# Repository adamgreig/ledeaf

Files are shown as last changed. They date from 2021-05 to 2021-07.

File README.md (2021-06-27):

# LEDEAF

A modular LED light inspired by [@GeekMomProjects]' project. Compared to the
original, this version:

* is drawn from scratch in KiCad
* uses the attaching bolts for electrical contact, instead of spring contacts
* only requires one acrylic sheet per triangle
* all LEDs on each panel are driven by the same input data

[@GeekMomProjects]: https://twitter.com/GeekMomProjects/status/1269671840512794624

The project is designed for complete SMT assembly by JLCPCB.

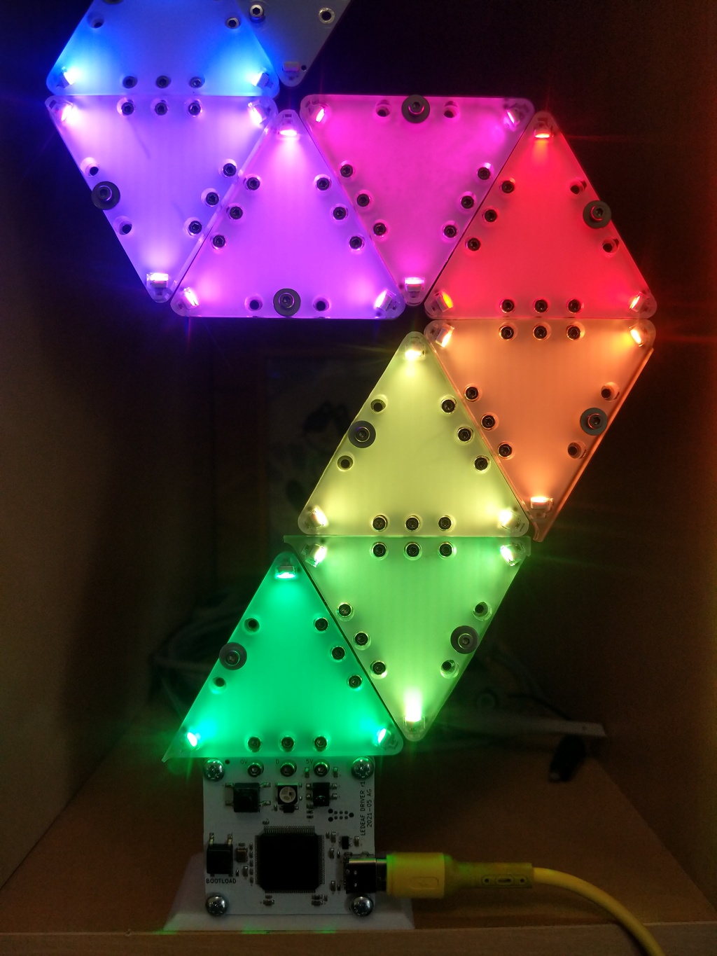
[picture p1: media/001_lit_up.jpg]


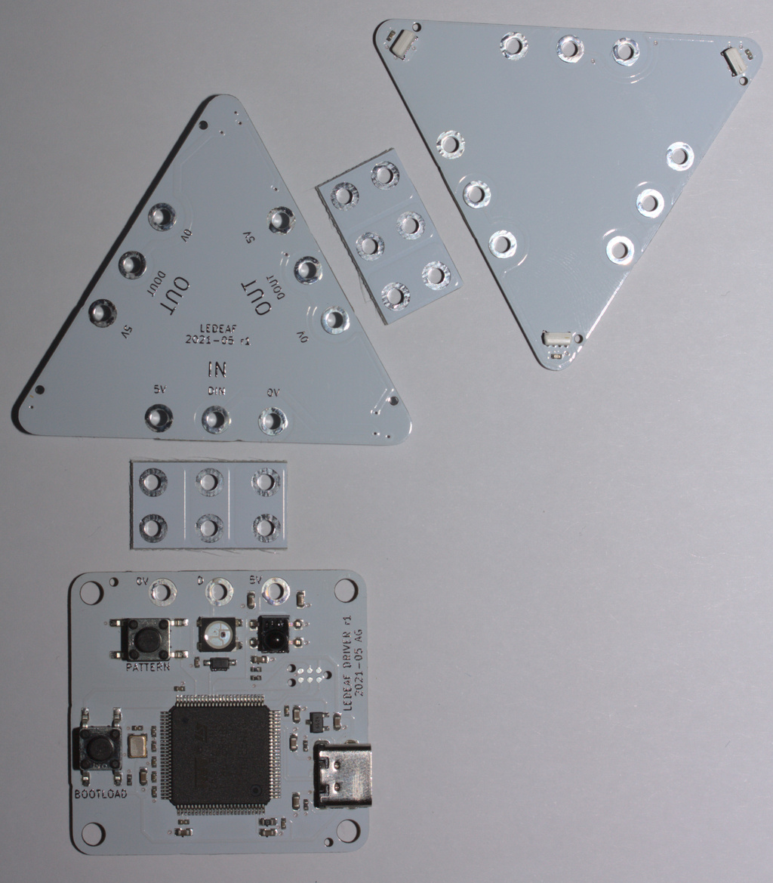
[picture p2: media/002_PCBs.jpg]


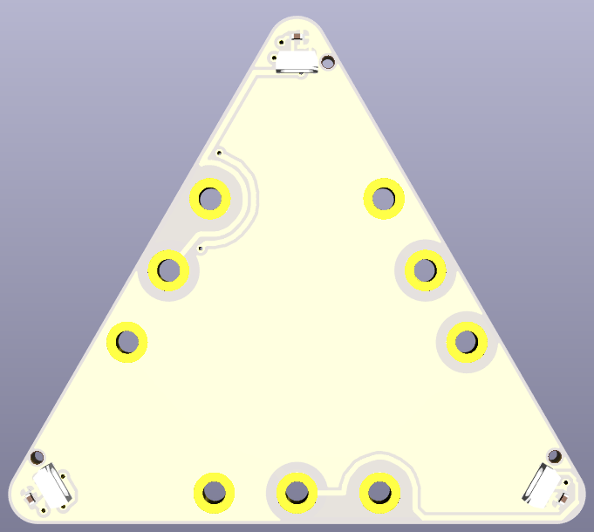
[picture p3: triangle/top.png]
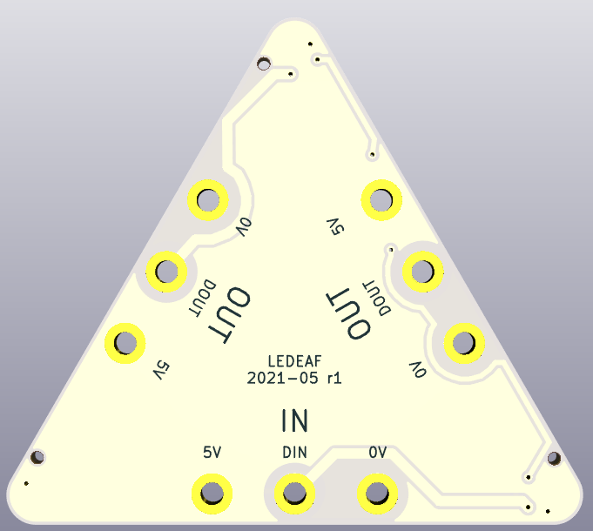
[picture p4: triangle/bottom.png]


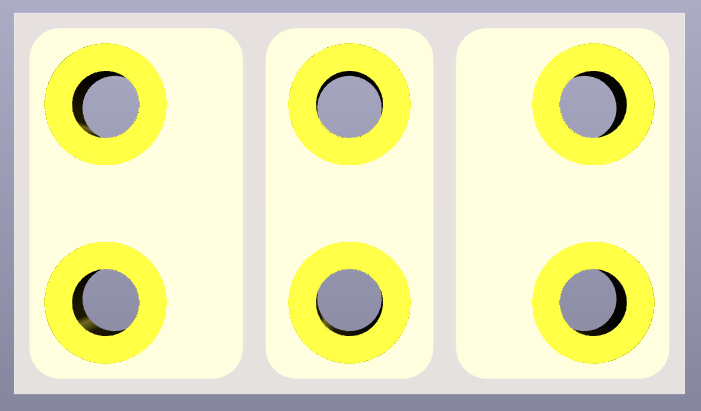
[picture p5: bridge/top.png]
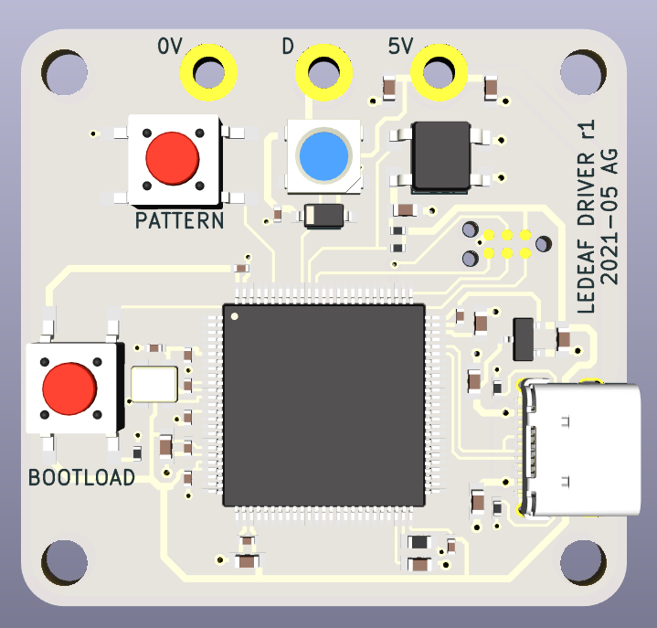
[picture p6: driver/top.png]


## License

Hardware designs licensed under the [CERN-OHL-P v2].

[CERN-OHL-P v2]: LICENSE_CERN_OHL_P_v2.txt

> You may redistribute and modify this documentation and make products
> using it under the terms of the CERN-OHL-P v2 (https:/cern.ch/cern-ohl).
> This documentation is distributed WITHOUT ANY EXPRESS OR IMPLIED
> WARRANTY, INCLUDING OF MERCHANTABILITY, SATISFACTORY QUALITY
> AND FITNESS FOR A PARTICULAR PURPOSE. Please see the CERN-OHL-P v2
> for applicable conditions

Software licensed under the [Mozilla Public License].

[Mozilla Public License]: LICENSE_MPL.txt

> This Source Code Form is subject to the terms of the Mozilla Public
> License, v. 2.0. If a copy of the MPL was not distributed with this
> file, You can obtain one at https://mozilla.org/MPL/2.0/.

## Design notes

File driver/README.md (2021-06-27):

# ledeaf driver

This directory contains the PCB design for the driver board.

## Revision 1: 2021-05

### Errata

* Issue going into USB bootloader possibly because BOOT1 (PB2) is floating,
  maybe add a pull-down resistor.

### Thoughts For Next Rev

* Combine BOOTLOAD and PATTERN buttons into one (wire BOOT0 up to a GPIO)
  to reduce BOM count.
* Investigate cheaper STM32 and oscillator.
* Add light sensor to allow automatically scaling brightness.

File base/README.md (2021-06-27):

# 3d Printed Base

This directory contains a design for a 3d printed holder for the driver PCB,
able to support a smallish stack of triangles. It has been printed successfully
in PLA, using M3 threaded heat-set inserts to attach to the driver PCB.

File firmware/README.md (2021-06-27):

# LEDEAF Firmware

Firmware for LEDEAF. Written in Rust.

## Build Requirements

* You must have a working Rust compiler installed. Visit
[rustup.rs](https://rustup.rs) to install Rust.

* Your Rust toolchain needs the `thumbv7em-none-eabihf` target installed:

```
rustup target add thumbv7em-none-eabihf
```

## Building and Flashing

To build the current firmware and flash using a connected probe, install
[`cargo-embed`](https://crates.io/crates/cargo-embed) and then run:

```
cargo embed --release
```

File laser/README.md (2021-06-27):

# Laser Cutter Drawings

This directory contains drawings for laser cutting the frosted acrylic top
covers for the triangle PCBs. The design material is a frosted/translucent 3mm
acrylic, but other thicknesses or styles could work.

One acrylic triangle is required per triangle PCB.

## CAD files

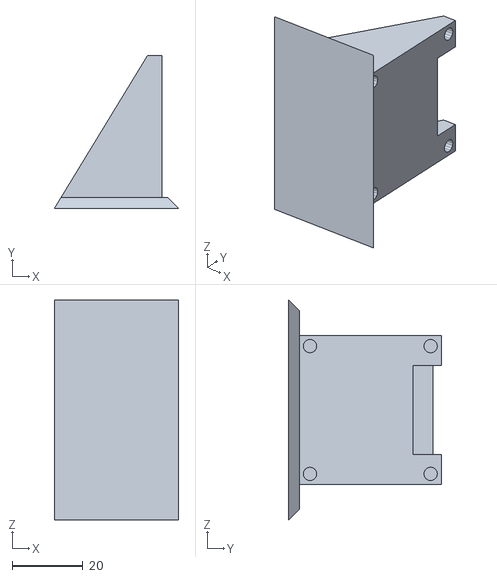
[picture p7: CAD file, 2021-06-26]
base/base.stl
35.0 x 43.0 x 62.0

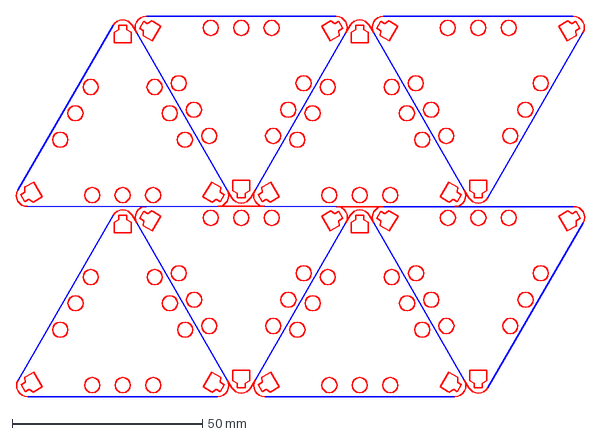
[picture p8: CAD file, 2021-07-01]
laser/cover_100x150.dxf
149.6 x 99.9 mm

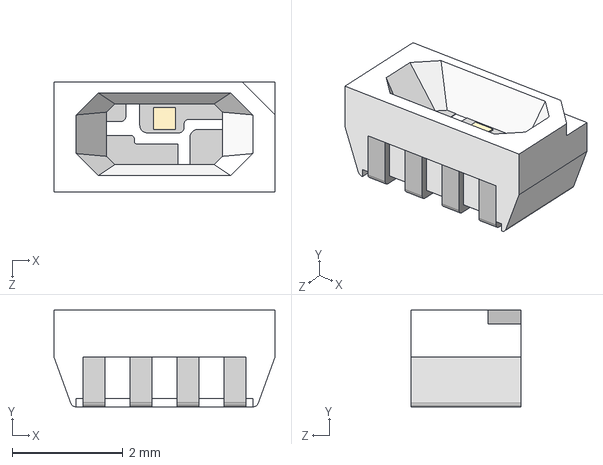
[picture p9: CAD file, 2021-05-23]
triangle/ws2812-4020.step
4.00 x 1.75 x 2.00 mm

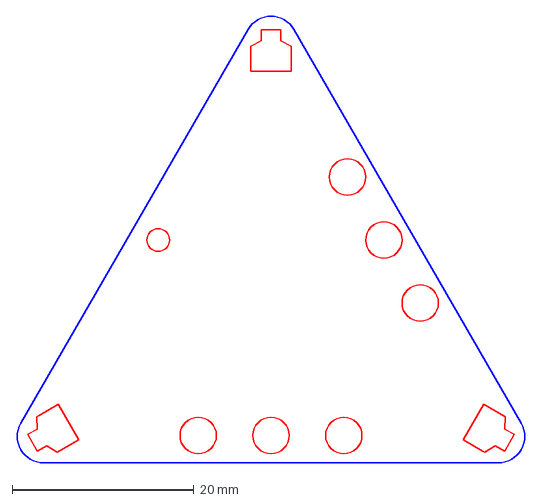
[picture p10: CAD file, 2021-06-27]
laser/cover.dxf
56.0 x 49.1 mm

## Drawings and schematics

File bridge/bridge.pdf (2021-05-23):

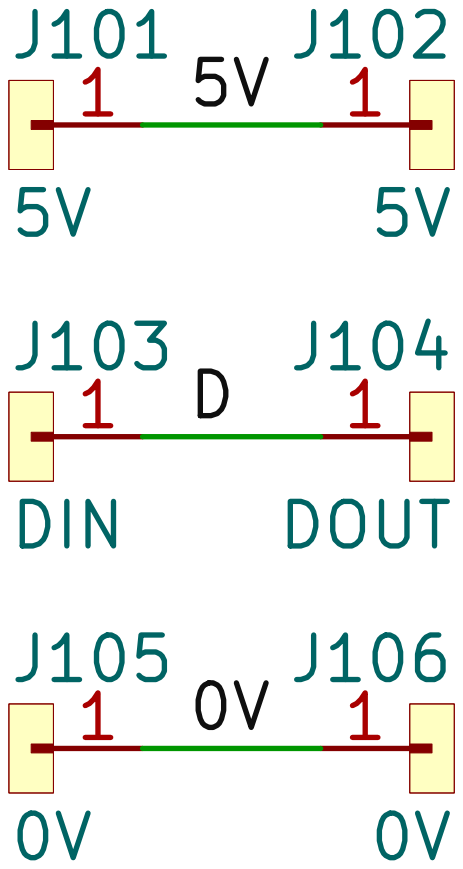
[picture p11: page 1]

File: bridge.kicad_sch Sheet: / Drawn By: AG

Id: 1/1 Title: LEDEAF Bridge PCB

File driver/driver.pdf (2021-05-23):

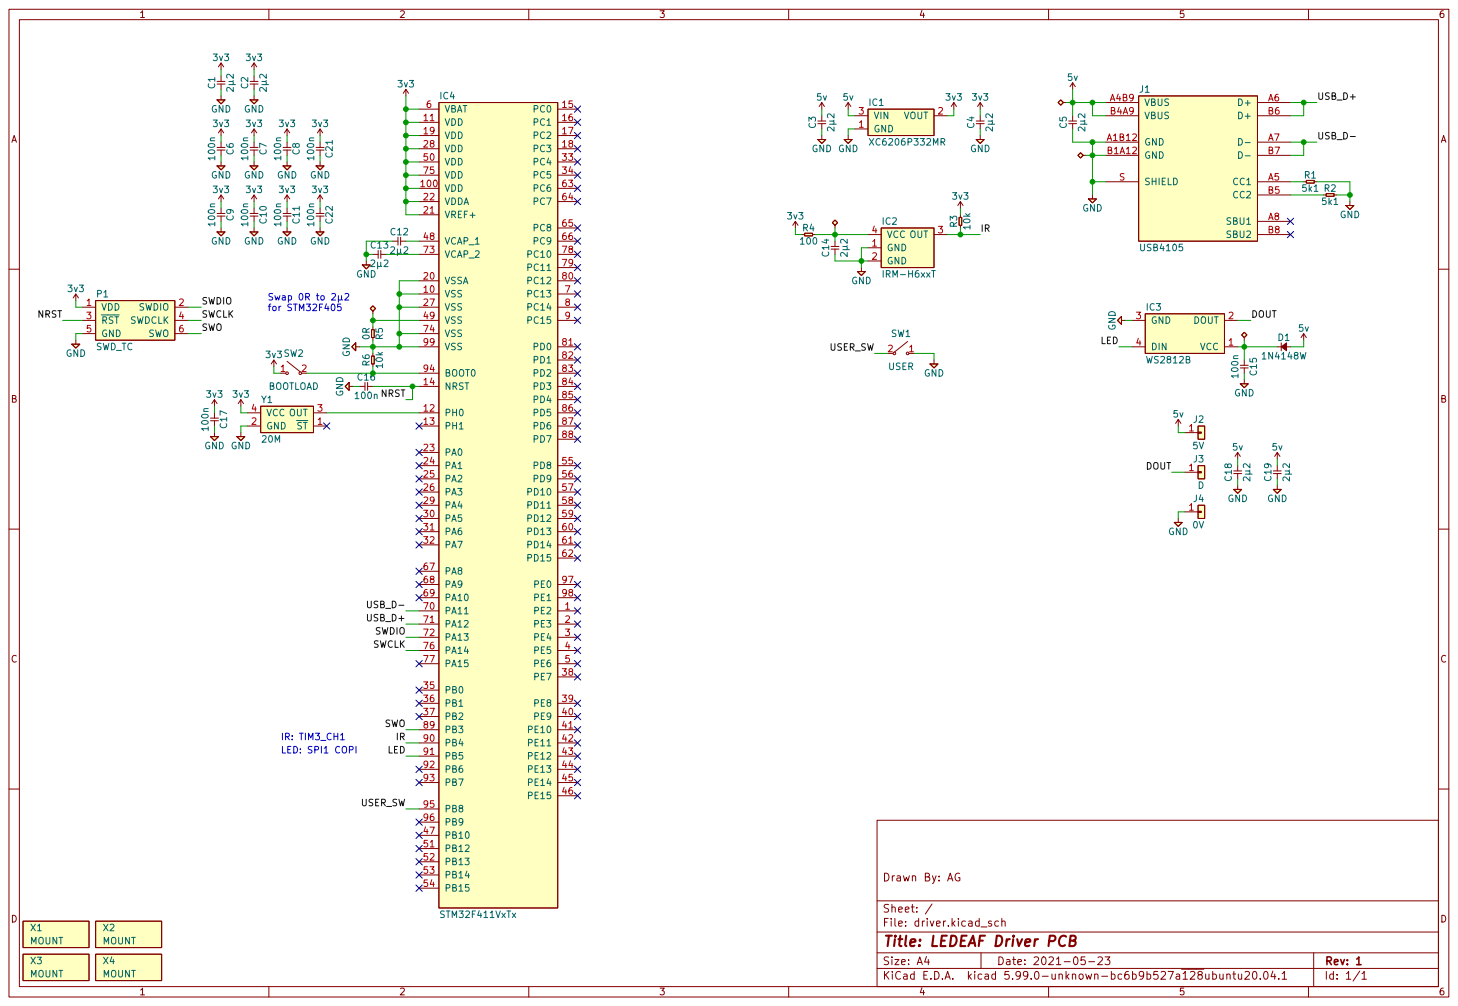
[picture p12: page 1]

File: driver.kicad_sch Sheet: / Drawn By: AG

Id: 1/1 Title: LEDEAF Driver PCB

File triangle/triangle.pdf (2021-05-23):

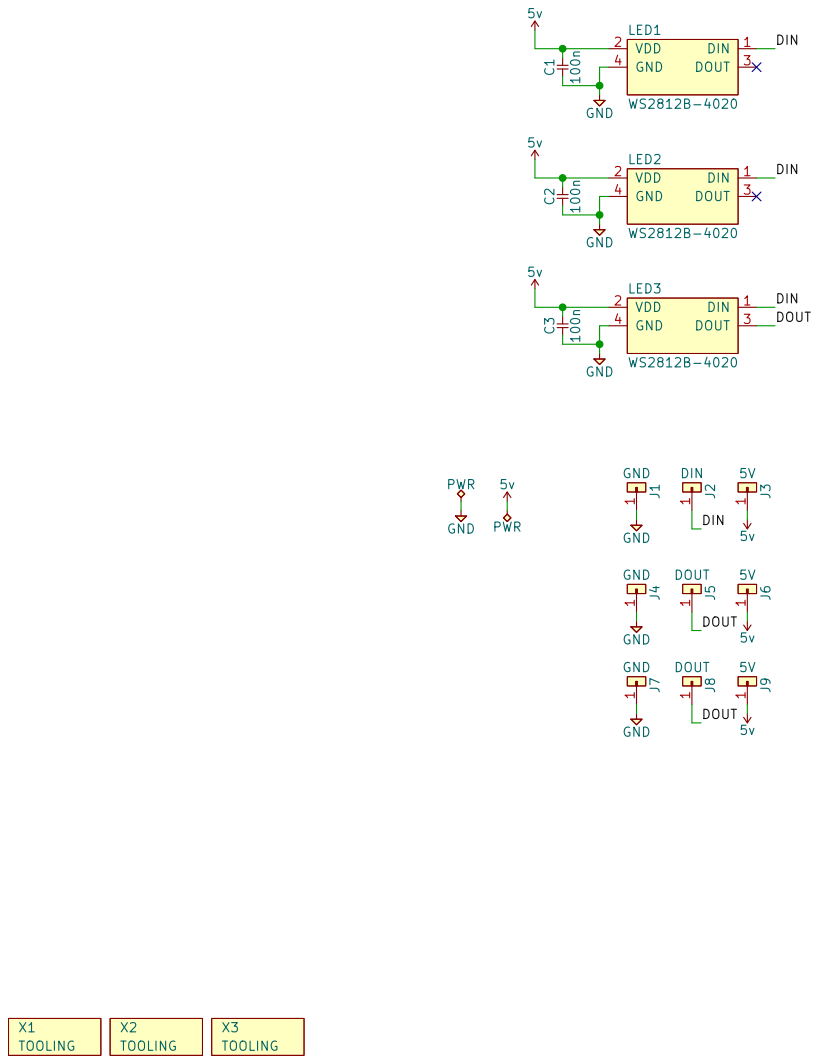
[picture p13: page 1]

File: triangle.kicad_sch Sheet: / Drawn By: AG

Id: 1/1 Title: LEDEAF Triangle PCB

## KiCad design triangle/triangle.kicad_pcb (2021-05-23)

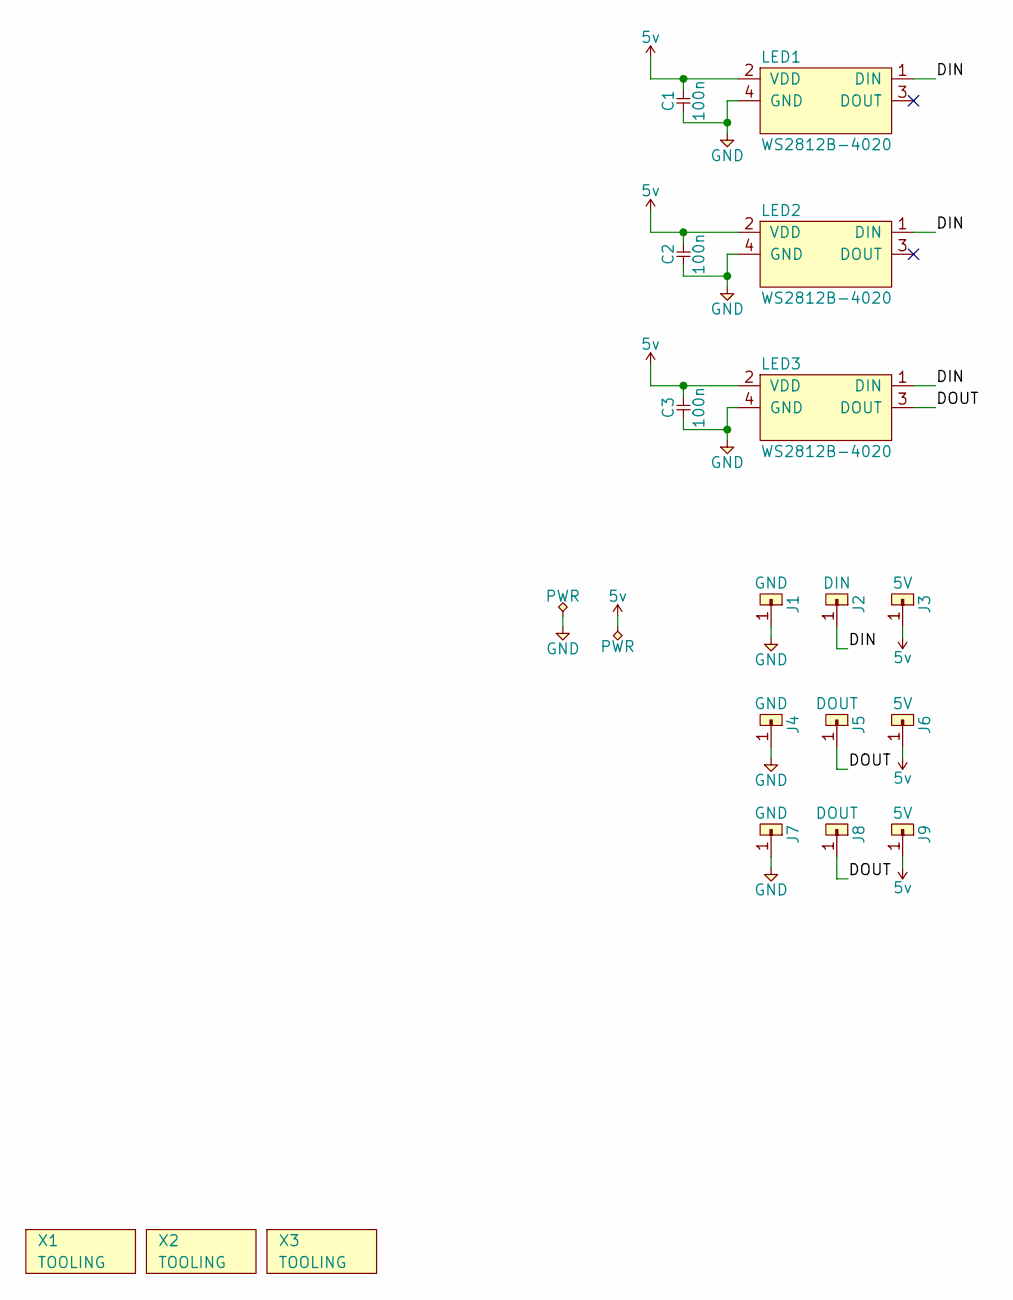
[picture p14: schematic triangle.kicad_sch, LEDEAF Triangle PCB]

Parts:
C1, C2, C3: 100n; 0402; LCSC C1525
J1, J4, J7: GND; M2_PTH
J2: DIN; M2_PTH
J3, J6, J9: 5V; M2_PTH
J5, J8: DOUT; M2_PTH
LED1, LED2, LED3: WS2812B-4020; LCSC C965557
X1, X2, X3: TOOLING; M2.5_HOLE

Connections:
5v: C1.2, C2.2, C3.2, J3.1, J6.1, J9.1, LED1.2 (VDD), LED2.2 (VDD), LED3.2 (VDD)
/DIN: J2.1, LED1.1 (DIN), LED2.1 (DIN), LED3.1 (DIN)
/DOUT: J5.1, J8.1, LED3.3 (DOUT)
GND: C1.1, C2.1, C3.1, J1.1, J4.1, J7.1, LED1.4 (GND), LED2.4 (GND), LED3.4 (GND)

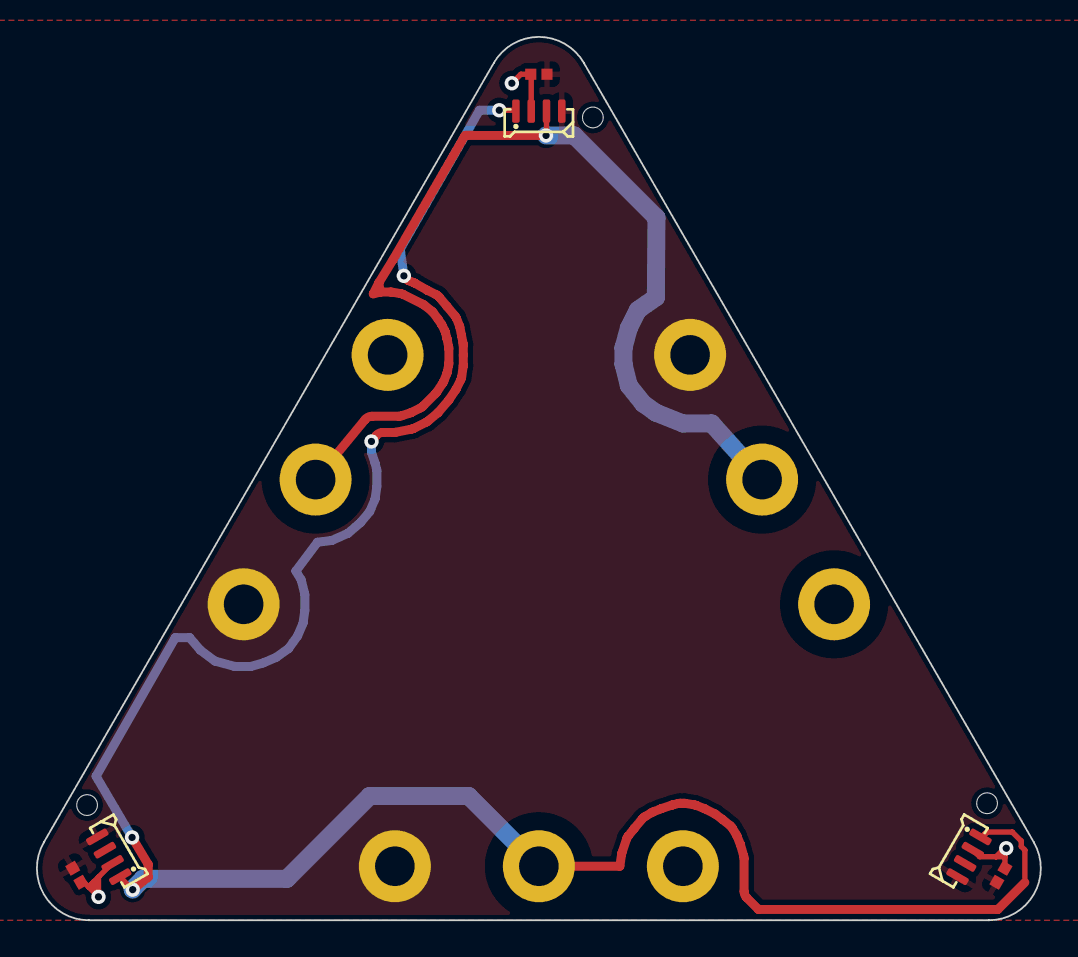
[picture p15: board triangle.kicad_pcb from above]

Board: 2 copper layers, 55.8 x 49.1 mm, 18 parts (0 on the bottom side), 4 nets.

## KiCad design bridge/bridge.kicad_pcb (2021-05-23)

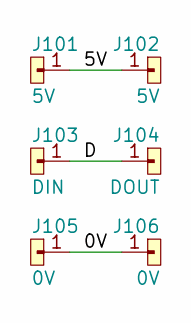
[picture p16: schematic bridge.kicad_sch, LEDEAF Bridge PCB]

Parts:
J101, J102: 5V; M2_PTH
J103: DIN; M2_PTH
J104: DOUT; M2_PTH
J105, J106: 0V; M2_PTH

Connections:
/0V: J105.1, J106.1
/5V: J101.1, J102.1
/D: J103.1, J104.1

Board: 2 copper layers, 6 parts (0 on the bottom side), 3 nets, no tracks yet.

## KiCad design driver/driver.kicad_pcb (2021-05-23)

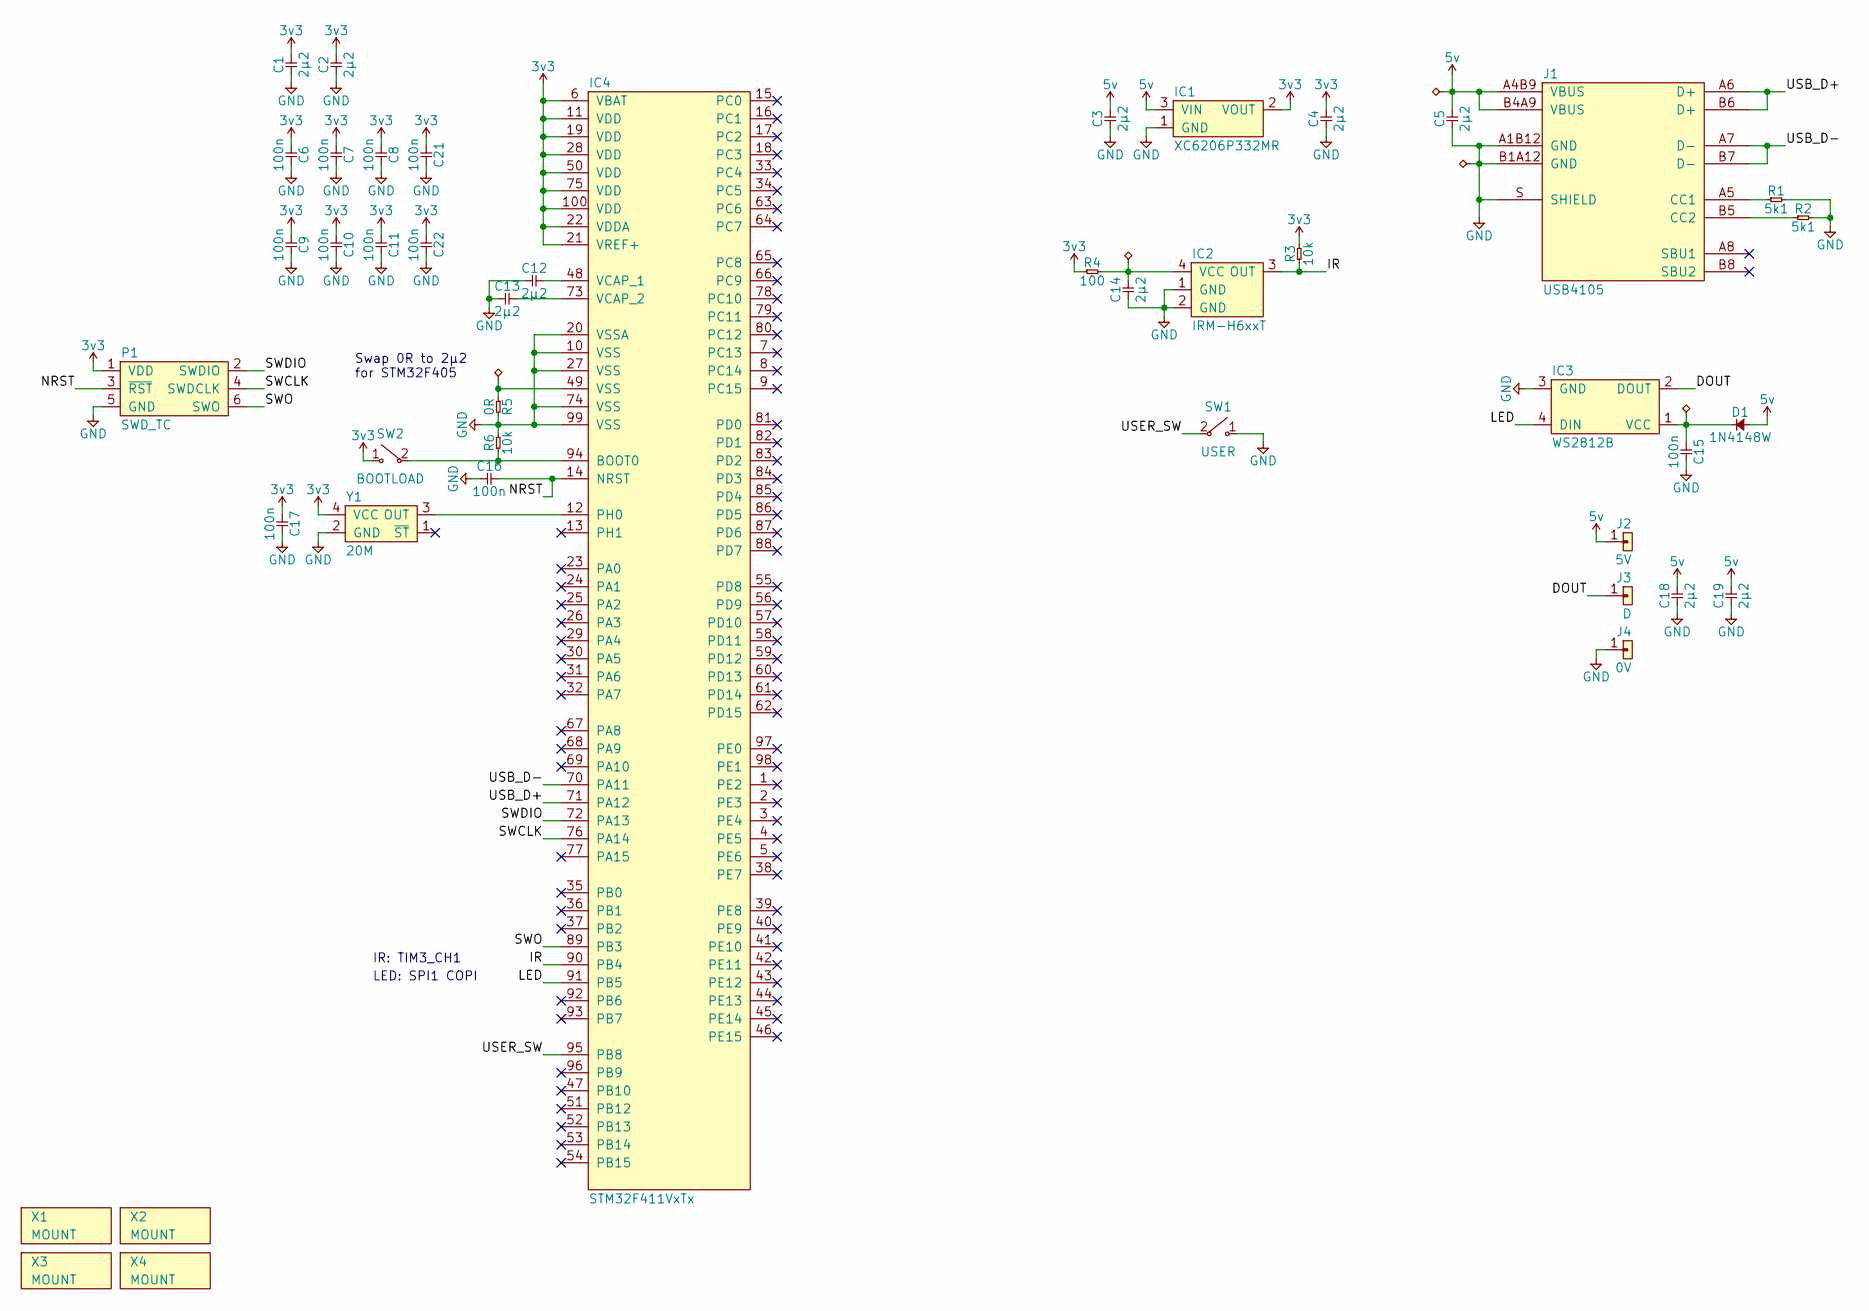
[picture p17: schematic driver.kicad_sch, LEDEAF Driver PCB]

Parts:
C1, C2, C3, C4, C5, C12, C13, C14, C18, C19: 2µ2; 0603; LCSC C23630
C6, C7, C8, C9, C10, C11, C15, C16, C17, C21, C22: 100n; 0402; LCSC C1525
D1: 1N4148W; SOD-123; LCSC C81598
IC1: XC6206P332MR; SOT-23; LCSC C5446
IC2: IRM-H6xxT; IRM-H6XXT; LCSC C390031
IC3: WS2812B; LCSC C114586
IC4: STM32F411VxTx; LQFP-100; LCSC C382005
J1: USB4105; LCSC C167321
J2: 5V; M2_PTH
J3: D; M2_PTH
J4: 0V; M2_PTH
P1: SWD_TC; TC2030-NL
R1, R2: 5k1; 0402; LCSC C25905
R3, R6: 10k; 0402; LCSC C25744
R4: 100; 0402; LCSC C25076
R5: 0R; 0603; LCSC C21189
SW1: USER; SW_MOM_6X6; LCSC C127509
SW2: BOOTLOAD; SW_MOM_6X6; LCSC C127509
X1, X2, X3, X4: MOUNT; M3_HOLE
Y1: 20M; XO-32x25; LCSC C32529

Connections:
3v3: C1.2, C2.2, C4.2, C6.1, C7.1, C8.1, C9.1, C10.1, C11.1, C17.1, C21.1, C22.1, IC1.2 (VOUT), IC4.6 (VBAT), IC4.11 (VDD), IC4.19 (VDD), IC4.21 (VREF+), IC4.22 (VDDA), IC4.28 (VDD), IC4.50 (VDD), IC4.75 (VDD), IC4.100 (VDD), P1.1 (VDD), R3.2, R4.1, SW2.1 ("~"), Y1.4 (VCC)
5v: C3.2, C5.2, C18.2, C19.2, D1.2, IC1.3 (VIN), J1.A4B9 (VBUS), J1.B4A9 (VBUS), J2.1
/DOUT: IC3.2 (DOUT), J3.1
/IR: IC2.3 (OUT), IC4.90 (PB4), R3.1
/LED: IC3.4 (DIN), IC4.91 (PB5)
/NRST: C16.2, IC4.14 (NRST), P1.3 (~RST)
/SWCLK: IC4.76 (PA14), P1.4 (SWDCLK)
/SWDIO: IC4.72 (PA13), P1.2 (SWDIO)
/SWO: IC4.89 (PB3), P1.6 (SWO)
/USB_D+: IC4.71 (PA12), J1.A6 (D+), J1.B6 (D+)
/USB_D-: IC4.70 (PA11), J1.A7 (D-), J1.B7 (D-)
/USER_SW: IC4.95 (PB8), SW1.2 ("~")
GND: C1.1, C2.1, C3.1, C4.1, C5.1, C6.2, C7.2, C8.2, C9.2, C10.2, C11.2, C12.1, C13.1, C14.1, C15.2, C16.1, C17.2, C18.1, C19.1, C21.2, C22.2, IC1.1 (GND), IC2.1 (GND), IC2.2 (GND), IC3.3 (GND), IC4.10 (VSS), IC4.20 (VSSA), IC4.27 (VSS), IC4.74 (VSS), IC4.99 (VSS), J1.A1B12 (GND), J1.B1A12 (GND), J1.S (SHIELD), J4.1, P1.5 (GND), R1.2, R2.2, R5.2, R6.2, SW1.1 ("~"), Y1.2 (GND)
unnamed: C12.2, IC4.48 (VCAP_1)
unnamed: C13.2, IC4.73 (VCAP_2)
unnamed: C14.2, IC2.4 (VCC), R4.2
unnamed: C15.1, D1.1, IC3.1 (VCC)
unnamed: J1.A5 (CC1), R1.1
unnamed: J1.B5 (CC2), R2.1
unnamed: IC4.49 (VSS), R5.1
unnamed: IC4.94 (BOOT0), R6.1, SW2.2 ("~")
unnamed: IC4.12 (PH0), Y1.3 (OUT)

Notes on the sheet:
Swap 0R to 2µ2 for STM32F405
IR: TIM3_CH1
LED: SPI1 COPI

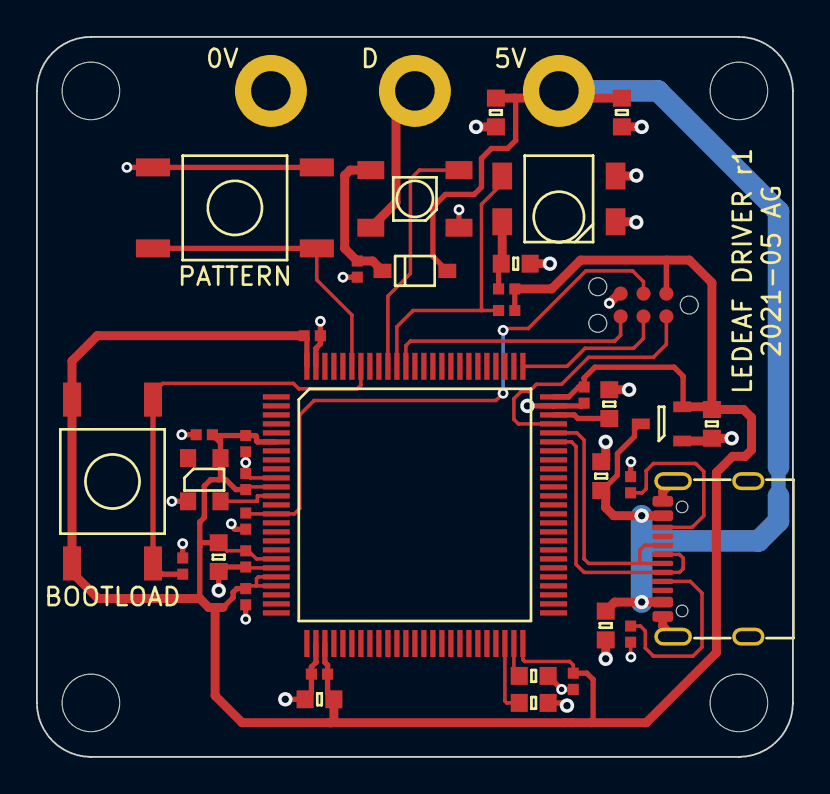
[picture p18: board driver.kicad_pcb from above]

Board: 2 copper layers, 42.0 x 40.0 mm, 44 parts (0 on the bottom side), 22 nets.

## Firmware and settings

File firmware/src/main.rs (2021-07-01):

//! Firmware for LEDEAF project.
//! Copyright 2021 Adam Greig.
//! Licensed under the Mozilla Public License v2.

#![no_std]
#![no_main]

use panic_halt as _;
use heapless::spsc::Queue;
use stm32f4xx_hal::prelude::*;
use stm32f4xx_hal::spi::{Spi, NoSck, NoMiso};
use stm32f4xx_hal::stm32::{self, interrupt};
use ws2812_spi::Ws2812;
use smart_leds::{brightness, SmartLedsWrite, RGB8, colors::*};
use choreographer::{script, engine::{LoopBehavior, Sequence}};
use groundhog::RollingTimer;
use rtt_target::rtt_init_print;

mod ir;
mod timer;
mod patterns;

use ir::{setup_tim3, process_tim3, Decoder as IRDecoder, Command as IRCommand};
use timer::{setup_tim5, Timer};
use patterns::Pattern;

/// Number of LED triangles to drive.
const N_LEDS: usize = 11;

/// Queue for moving received IR commands into the main thread.
static mut IRCOMMAND_Q: Queue<IRCommand, 8> = Queue::new();

#[cortex_m_rt::entry]
fn main() -> ! {
    // Set up STM32 and peripherals.
    rtt_init_print!();
    let dp = stm32::Peripherals::take().unwrap();
    dp.RCC.apb1enr.modify(|_, w| w.tim3en().enabled().tim5en().enabled());
    let rcc = dp.RCC.constrain();
    let clocks = rcc.cfgr.use_hse(20.mhz()).sysclk(48.mhz()).freeze();
    let gpiob = dp.GPIOB.split();
    let led = gpiob.pb5.into_alternate_af5();
    let _ir = gpiob.pb4.into_alternate_af2();
    let spi = Spi::spi1(dp.SPI1, (NoSck, NoMiso, led), ws2812_spi::MODE, 3_000_000.hz(), clocks);
    let mut ws = Ws2812::new(spi);

    // Grab the consumer half of the IR command queue.
    let mut ir_consumer = unsafe { IRCOMMAND_Q.split().1 };

    // Set up TIM3 CH1 for IR pulse capture, and TIM5 to provide a timebase.
    setup_tim3(&clocks, &dp.TIM3);
    setup_tim5(&clocks, &dp.TIM5);

    // Storage for LED patterns.
    let mut leds: [Sequence<Timer, 32>; N_LEDS] = Sequence::new_array();
    let mut driver_led: Sequence<Timer, 8> = Sequence::empty();
    let mut data: [RGB8; 1 + N_LEDS] = Default::default();

    // Clear all LEDs at startup.
    ws.write(data.iter().cloned()).ok();
    cortex_m::asm::delay(20_000);

    // Start on the colour wheel pattern.
    Pattern::Strobe.set(&mut leds);

    let loop_timer = Timer {};
    let mut level = 100u8;
    let mut running = true;

    loop {
        let t0 = loop_timer.get_ticks();

        // Process any incoming IR commands.
        if let Some(cmd) = ir_consumer.dequeue() {
            if running {
                use Pattern::Solid;
                match cmd {
                    IRCommand::DimUp                => { level = level.saturating_add(10); },
                    IRCommand::DimDown              => { level = level.saturating_sub(10); },
                    IRCommand::Strobe               => { Pattern::Strobe.set(&mut leds); },
                    IRCommand::Flash                => { Pattern::Flash.set(&mut leds); },
                    IRCommand::Smooth               => { Pattern::Smooth.set(&mut leds); },
                    IRCommand::Fade                 => { Pattern::Fade.set(&mut leds); },
                    IRCommand::Red                  => { Solid(RED).set(&mut leds); },
                    IRCommand::Green                => { Solid(GREEN).set(&mut leds) },
                    IRCommand::Blue                 => { Solid(BLUE).set(&mut leds) },
                    IRCommand::White                => { Solid(WHITE).set(&mut leds) },
                    IRCommand::LightRed             => { Solid(FIREBRICK).set(&mut leds) },
                    IRCommand::LightGreen           => { Solid(LIME_GREEN).set(&mut leds) },
                    IRCommand::LightBlue            => { Solid(DODGER_BLUE).set(&mut leds) },
                    IRCommand::Orange               => { Solid(DARK_RED).set(&mut leds) },
                    IRCommand::Cyan                 => { Solid(CYAN).set(&mut leds) },
                    IRCommand::Purple               => { Solid(MAGENTA).set(&mut leds) },
                    IRCommand::LightOrange          => { Solid(ORANGE_RED).set(&mut leds) },
                    IRCommand::Cerulean             => { Solid(DEEP_SKY_BLUE).set(&mut leds) },
                    IRCommand::LightPurple          => { Solid(PURPLE).set(&mut leds) },
                    IRCommand::Yellow               => { Solid(ORANGE).set(&mut leds) },
                    IRCommand::SeaGreen             => { Solid(SEA_GREEN).set(&mut leds) },
                    IRCommand::Pink                 => { Solid(DEEP_PINK).set(&mut leds) },
                    IRCommand::Off                  => {
                        running = false;
                        Pattern::Off.set(&mut leds);
                    },
                    _                               => (),
                }
            } else {
                if matches!(cmd, IRCommand::On) {
                    running = true;
                    Pattern::Strobe.set(&mut leds);
                }
            }
            driver_led.set(&script!(
                |    action |  color | duration_ms | period_ms_f | phase_offset_ms | repeat |
                |   fade_up |  GREEN |          50 |         0.0 |               0 |   once |
                |     solid |  GREEN |          50 |         0.0 |               0 |   once |
                |      seek |  BLACK |          50 |         0.0 |               0 |   once |
            ), LoopBehavior::OneShot);
        }

        // Run driver LED sequence.
        data[0] = driver_led.poll().unwrap_or(BLACK);

        // Run triangle LED sequences.
        for (led, entry) in leds.iter_mut().zip(&mut data[1..].iter_mut()) {
            *entry = led.poll().unwrap_or(BLACK);
        }

        // Write out LED data, at scaled brightness.
        // Disable interrupt processing while we send the SPI data to prevent timing glitches.
        cortex_m::interrupt::free(|_| ws.write(brightness(data.iter().cloned(), level)).ok());

        // Maintain 100fps; no need to render any faster than that.
        while loop_timer.millis_since(t0) < 10 {}
    }
}

/// We run an IR protocol decoder in the TIM3 interrupt handler,
/// capturing the received pulse widths and decoding them to commands.
#[interrupt]
fn TIM3() {
    static mut DECODER: IRDecoder = IRDecoder::new();
    let producer = unsafe { IRCOMMAND_Q.split().0 };
    process_tim3(DECODER, producer);
}

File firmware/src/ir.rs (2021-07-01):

//! NEC protocol IR decoding.

use core::convert::TryFrom;
use stm32f4xx_hal::stm32;
use groundhog::RollingTimer;
use crate::timer::Timer;

/// Configure TIM3 to capture rising and falling edges from an IR receiver.
pub fn setup_tim3(clocks: &stm32f4xx_hal::rcc::Clocks, tim3: &stm32::TIM3) {
    // Enable interrupt on update, CC1, and CC2.
    tim3.dier.write(|w| w.uie().enabled().cc1ie().enabled().cc2ie().enabled());
    unsafe { cortex_m::peripheral::NVIC::unmask(stm32::Interrupt::TIM3) };

    // Set up input capture from TI1 on both CC1 and CC2.
    tim3.ccmr1_input().write(|w| w.cc1s().ti1().cc2s().ti1());

    // Set CC1 to falling edge and CC2 to rising edge.
    tim3.ccer.write(|w| w.cc1e().set_bit().cc1p().set_bit().cc2e().set_bit());

    // Enable slave mode to reset on falling edge.
    tim3.smcr.write(|w| w.ts().ti1fp1().sms().reset_mode());

    // Divide clock to 1MHz, so that each tick is 1µs and we overflow every 65ms.
    let psc = (clocks.pclk1().0 / 1_000_000) as u16;
    tim3.psc.write(|w| w.psc().bits(psc - 1));

    // Set ARR to max.
    tim3.arr.write(|w| w.arr().bits(0xFFFF));

    // Trigger update event.
    tim3.egr.write(|w| w.ug().update());

    // Enable counter, and set URS=1 to only generate updates on overflow,
    // not on slave-mode resets.
    tim3.cr1.write(|w| w.cen().enabled().urs().counter_only());
}

pub fn process_tim3(decoder: &mut Decoder, mut producer: heapless::spsc::Producer<Command, 8>) {
    let ptr = stm32::TIM3::ptr();

    // Clear interrupt bits to acknowledge the interrupt.
    let sr = unsafe { (*ptr).sr.read() };
    unsafe { (*ptr).sr.modify(|_, w|
        w.uif().clear_bit().cc1if().clear_bit().cc2if().clear_bit()
    )};

    if sr.uif().bit_is_set() {
        // Reset decoder state machine on timer overflow.
        // The timer is reset after each pulse, so an overflow means
        // no edge was received for the entire timer period of 65ms.
        decoder.reset();
    }

    if sr.cc2if().bit_is_set() {
        // Rising edge detected, indicating the end of a mark pulse.
        let cc2 = unsafe { (*ptr).ccr2.read().ccr().bits() };
        decoder.mark(cc2);
    }

    if sr.cc1if().bit_is_set() {
        // Falling edge detected, indicating the end of a space pulse.
        // The timer is re
        let cc1 = unsafe { (*ptr).ccr1.read().ccr().bits() };
        if let Some(cmd) = decoder.space(cc1) {
            if let Ok(cmd) = Command::try_from(cmd) {
                producer.enqueue(cmd).ok();
            }
        }
    }
}

#[derive(Copy, Clone, Debug, num_enum::IntoPrimitive, num_enum::TryFromPrimitive)]
#[repr(u8)]
pub enum Command {
    DimUp       = 0x00,
    DimDown     = 0x01,
    Off         = 0x02,
    On          = 0x03,
    Red         = 0x04,
    Green       = 0x05,
    Blue        = 0x06,
    White       = 0x07,
    LightRed    = 0x08,
    LightGreen  = 0x09,
    LightBlue   = 0x0A,
    Flash       = 0x0B,
    Orange      = 0x0C,
    Cyan        = 0x0D,
    Purple      = 0x0E,
    Strobe      = 0x0F,
    LightOrange = 0x10,
    Cerulean    = 0x11,
    LightPurple = 0x12,
    Fade        = 0x13,
    Yellow      = 0x14,
    SeaGreen    = 0x15,
    Pink        = 0x16,
    Smooth      = 0x17,

}

#[derive(Copy, Clone, Debug)]
enum State {
    Reset,
    Addr { idx: usize, addr: u16 },
    Cmd  { idx: usize, cmd: u16 },
}

pub struct Decoder {
    state: State,
    last_mark: Option<u16>,
    last_cmd: Option<(u32, u8)>,
}

impl Decoder {
    const HEADER_MARK: i32 = 9000;
    const HEADER_SPACE: i32 = 4500;
    const REPEAT_SPACE: i32 = 2250;
    const BIT_MARK: i32 = 562;
    const SPACE_0: i32 = 1687;
    const SPACE_1: i32 = 562;
    const HEADER_TOL: i32 = 300;
    const BIT_TOL: i32 = 150;

    pub const fn new() -> Self {
        Self { state: State::Reset, last_mark: None, last_cmd: None }
    }

    /// Call when a mark pulse is received, with the width in µs.
    pub fn mark(&mut self, width: u16) {
        match self.last_mark {
            Some(_) => self.reset(),
            None    => self.last_mark = Some(width),
        }
    }

    /// Call when a space pulse is received, with the total mark+space time in µs.
    ///
    /// If a valid command has been fully decoded, returns Some(u8).
    pub fn space(&mut self, width: u16) -> Option<u8> {
        match self.last_mark {
            Some(mark) => {
                self.last_mark = None;
                self.process(mark as i32, (width - mark) as i32)
            },
            None => {
                self.reset();
                None
            },
        }
    }

    /// Call after a timeout to reset the decoder state.
    pub fn reset(&mut self) {
        self.state = State::Reset;
        self.last_mark = None;
    }

    fn process_bit(mark: i32, space: i32) -> Option<u16> {
        if (mark - Self::BIT_MARK).abs() < Self::BIT_TOL {
            if (space - Self::SPACE_0).abs() < Self::BIT_TOL {
                Some(0)
            } else if (space - Self::SPACE_1).abs() < Self::BIT_TOL {
                Some(1)
            } else {
                None
            }
        } else {
            None
        }
    }

    fn process_word(mark: i32, space: i32, idx: usize, mut word: u16)
        -> Option<u16>
    {
        let bit = match Self::process_bit(mark, space) {
            Some(bit) => bit,
            None      => return None,
        };
        word |= bit << idx;
        Some(word)
    }

    fn process(&mut self, mark: i32, space: i32) -> Option<u8> {
        // Discard stale last_cmds.
        let timer = Timer {};
        if let Some((t0, _)) = self.last_cmd {
            if timer.millis_since(t0) > 200 {
                self.last_cmd = None;
            }
        }

        match self.state {
            State::Reset => {
                if ((mark  - Self::HEADER_MARK ).abs() < Self::HEADER_TOL) &&
                   ((space - Self::HEADER_SPACE).abs() < Self::HEADER_TOL)
                {
                    // Header received, prepare to receive an address.
                    self.state = State::Addr { idx: 0, addr: 0 };
                } else if ((mark  - Self::HEADER_MARK ).abs() < Self::HEADER_TOL) &&
                          ((space - Self::REPEAT_SPACE).abs() < Self::HEADER_TOL)
                {
                    // Repeat command received, check if we have a recent command to repeat.
                    if let Some((_, cmd)) = self.last_cmd {
                        // Reset timeout and return the last command.
                        self.last_cmd = Some((timer.get_ticks(), cmd));
                        return Some(cmd);
                    }
                }
            },

            State::Addr { idx, addr } => {
                let addr = match Self::process_word(mark, space, idx, addr) {
                    Some(addr) => addr,
                    None => { self.reset(); return None; },
                };
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

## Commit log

2021-05-23 Initial commit. First version of triangle PCB.
    [JLCSMT_BOM.xlsx, triangle.kicad_pcb, triangle.kicad_sch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]
2021-05-23 Add tooling holes
    [triangle.kicad_pcb, triangle.kicad_sch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]
2021-05-23 Update triangle board to put LED centroid at footprint origin
    [JLCSMT_BOM.xlsx, triangle.kicad_pcb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]
2021-05-23 Add nightly version of bridge, but probably soon to be deleted
    [bridge.kicad_pcb, bridge.kicad_sch]
2021-05-23 Update bridge to use rectangular PCB for v-score
    [bridge.kicad_pcb]
2021-05-23 Add driver PCB
    [JLCSMT_BOM.xlsx, driver.kicad_pcb, driver.kicad_sch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]
2021-05-23 Update page info boxes
    [bridge.kicad_pcb, bridge.kicad_sch, triangle.kicad_pcb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]
2021-05-23 Add WS2812-4020 3d model, update render
    [triangle.kicad_pcb, ws2812-4020.step]
2021-06-03 Add prototype laser cut cover
    [cover.dxf]
2021-06-05 Add 100x150 sheet for laser cutting
    [cover_100x150.dxf]
2021-06-24 Remove bounding box from laser cut 100x150 sheet
    [cover_100x150.dxf]
2021-06-26 Add 300x300 sheet of laser covers, add 3d printed base mount
    [base.stl]
2021-06-26 Try out using choreographer to sequence the LEDs
2021-06-27 Fix max number of states in each sequence
    [main.rs]
2021-06-27 Add README for driver PCB
2021-06-27 Add some more READMEs, update cover.dxf to new M2-clear third hole design, licence firmware under MPL2, tidy up firmware.
    [cover.dxf]
2021-06-27 Swap to 100fps fixed-rate rendering
    [main.rs]
2021-06-27 Swap to a 32-bit TIM5 instead of SysTick for timebase; extract IR decoding into its own module.
    [ir.rs, main.rs]
2021-06-27 Refactor timer and IR stuff out of main.rs
2021-07-01 Update cut order on cover_100x150
    [cover_100x150.dxf]
